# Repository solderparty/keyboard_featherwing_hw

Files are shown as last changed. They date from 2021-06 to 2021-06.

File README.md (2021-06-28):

# The Keyboard FeatherWing (Rev 2)

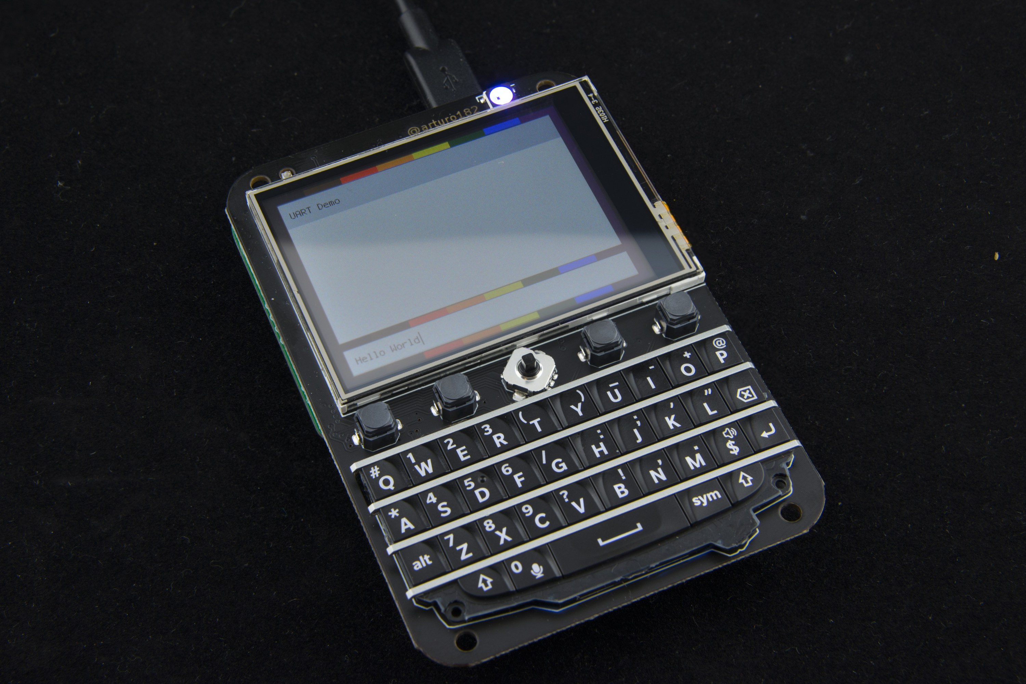
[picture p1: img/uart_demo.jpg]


The Keyboard FeatherWing is an easy way to add a handheld Qwerty keyboard and a 2.6” color display (+ more) to your project! It fits well in your hands and is great for typing with your thumbs, early 2000s-style.

The FeatherWing itself does not contain an MCU/CPU/SoC that you can program; you will need a board compatible with the [Adafruit Feather System](https://learn.adafruit.com/adafruit-feather/feather-specification).

For revision 1, see the tag `rev1`.

# Technical details
- 2.6” 320x240 16-bit color LCD with resistive touch screen
- QWERTY keyboard
- 5-way button
- 4 soft tactile buttons
- A Neopixel
- microSD connector
- Stemma QT/Qwiic connector
- An Ambient Light Sensor
- On/Off switch
- Dual row sockets
- Four mounting holes
- GPIO solder jumpers

# Links

For more information visit https://kfw.solder.party/

You can find example code here: https://github.com/solderparty/keyboard_featherwing_sw

This board uses an ATSAMD20 chip as a i2c peripheral that can be polled to get the key FIFO, as well as used as a simple GPIO Expander, the firmware for the SAM can be found here: https://github.com/solderparty/bbq10kbd_i2c_sw

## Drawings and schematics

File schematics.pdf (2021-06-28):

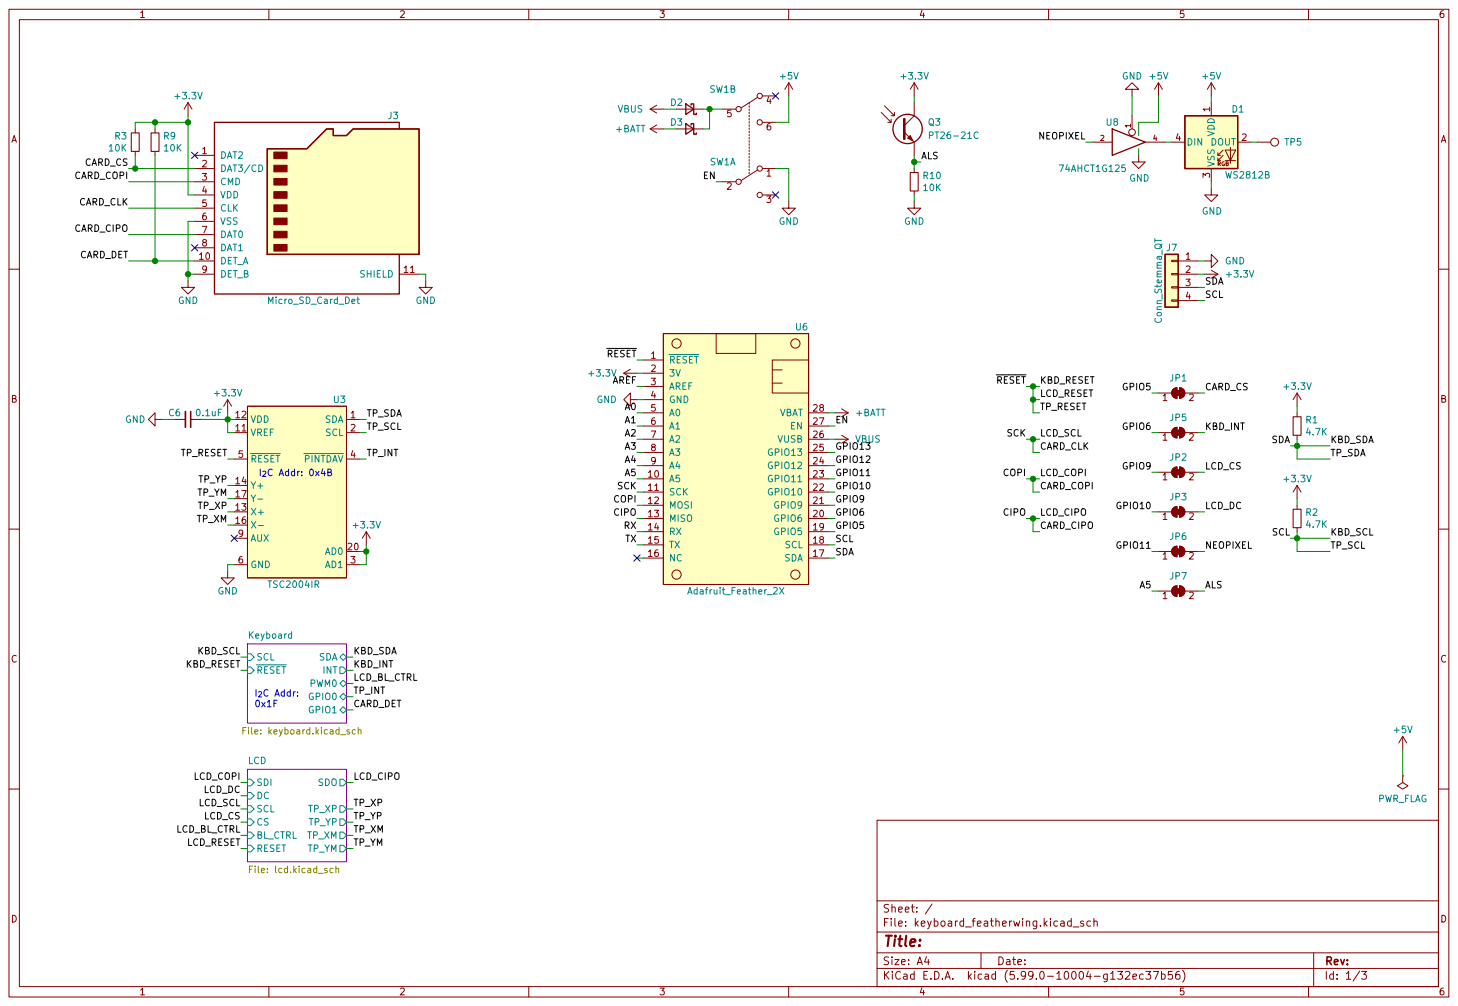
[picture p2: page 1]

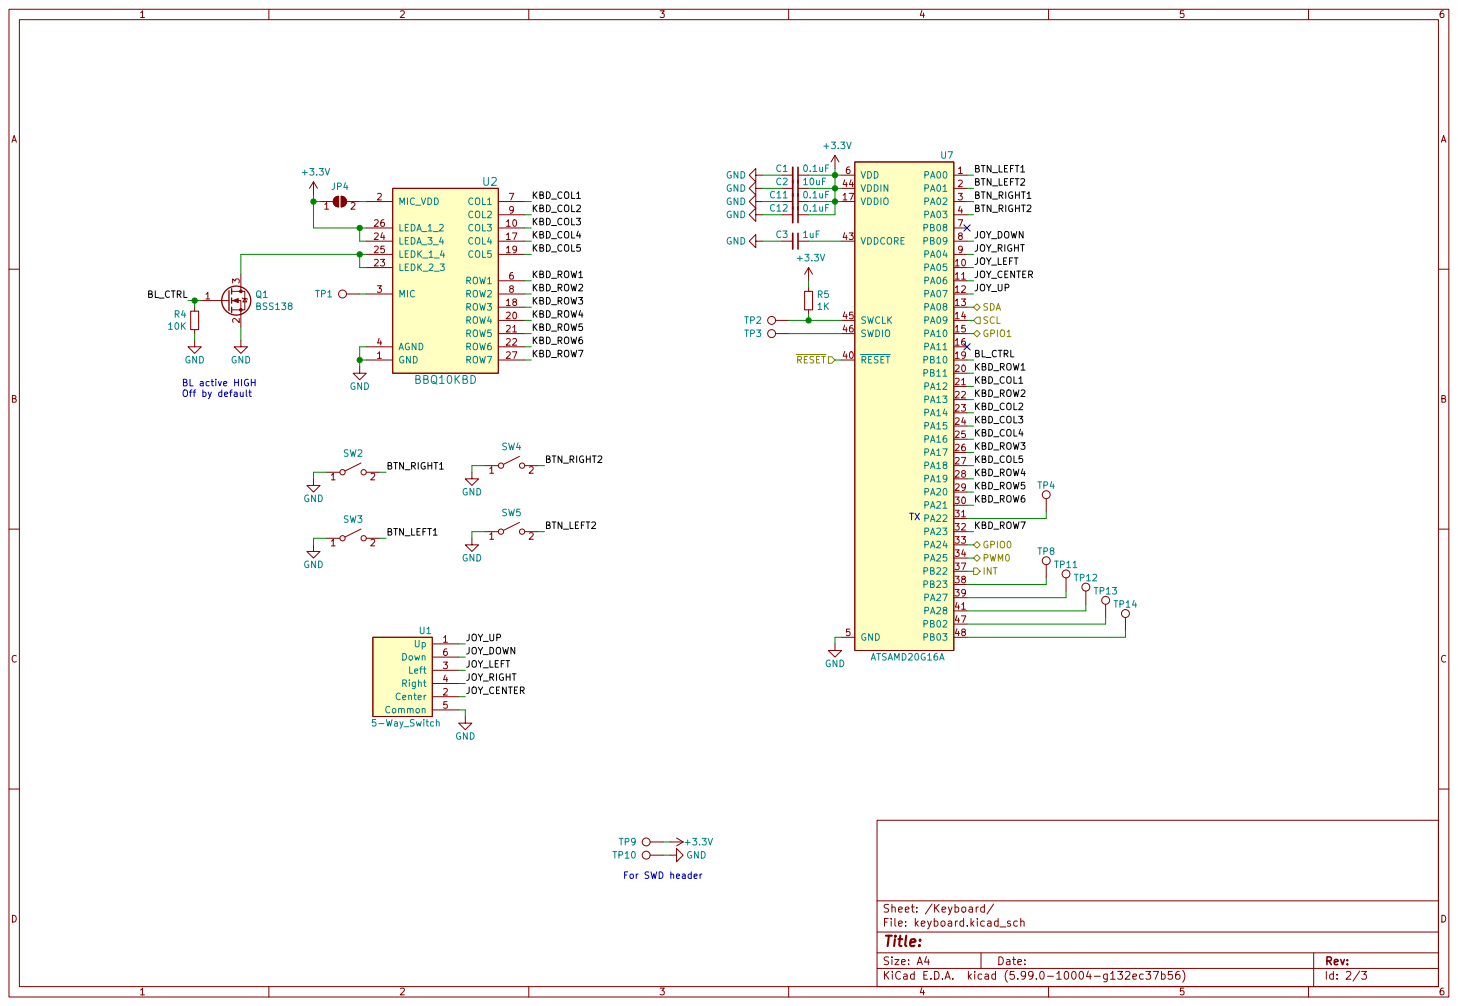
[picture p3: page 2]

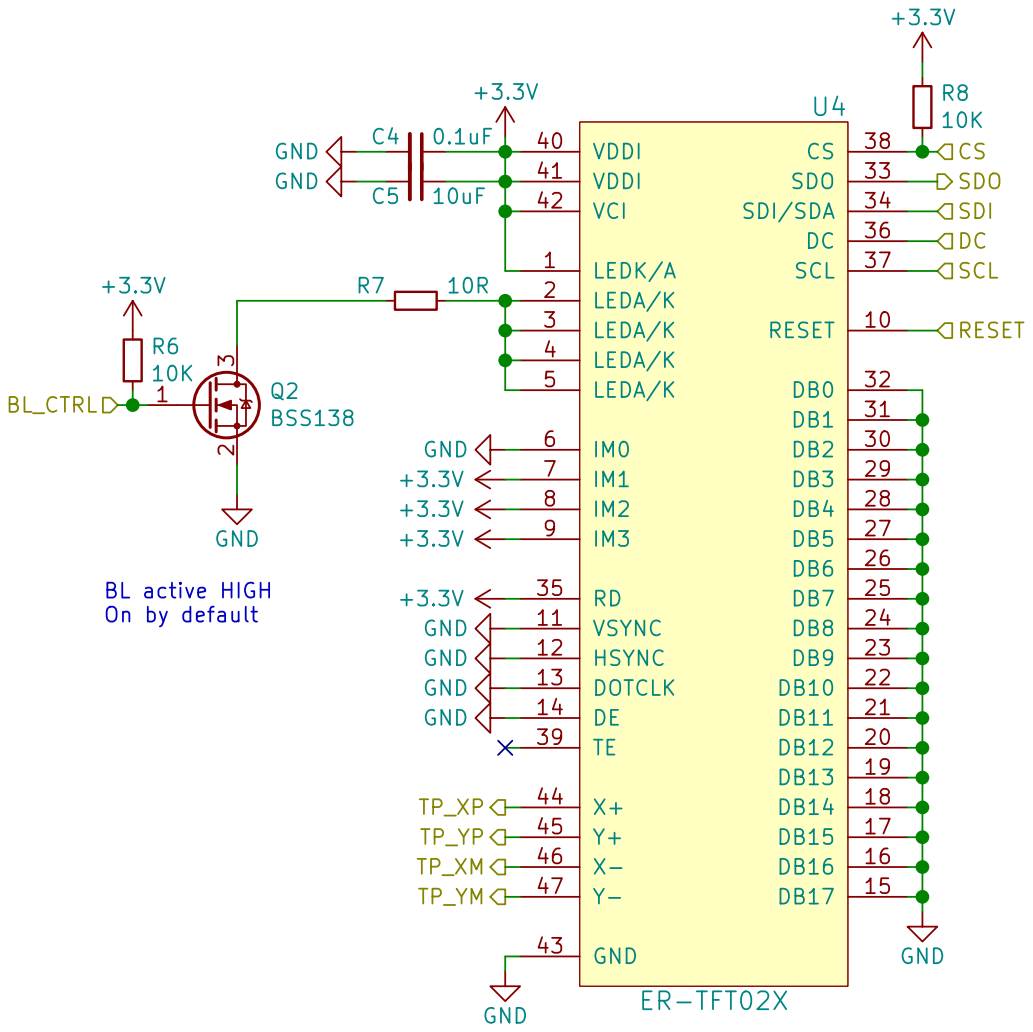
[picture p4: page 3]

File: lcd.kicad_sch Sheet: /LCD/
Id: 3/3 Title:

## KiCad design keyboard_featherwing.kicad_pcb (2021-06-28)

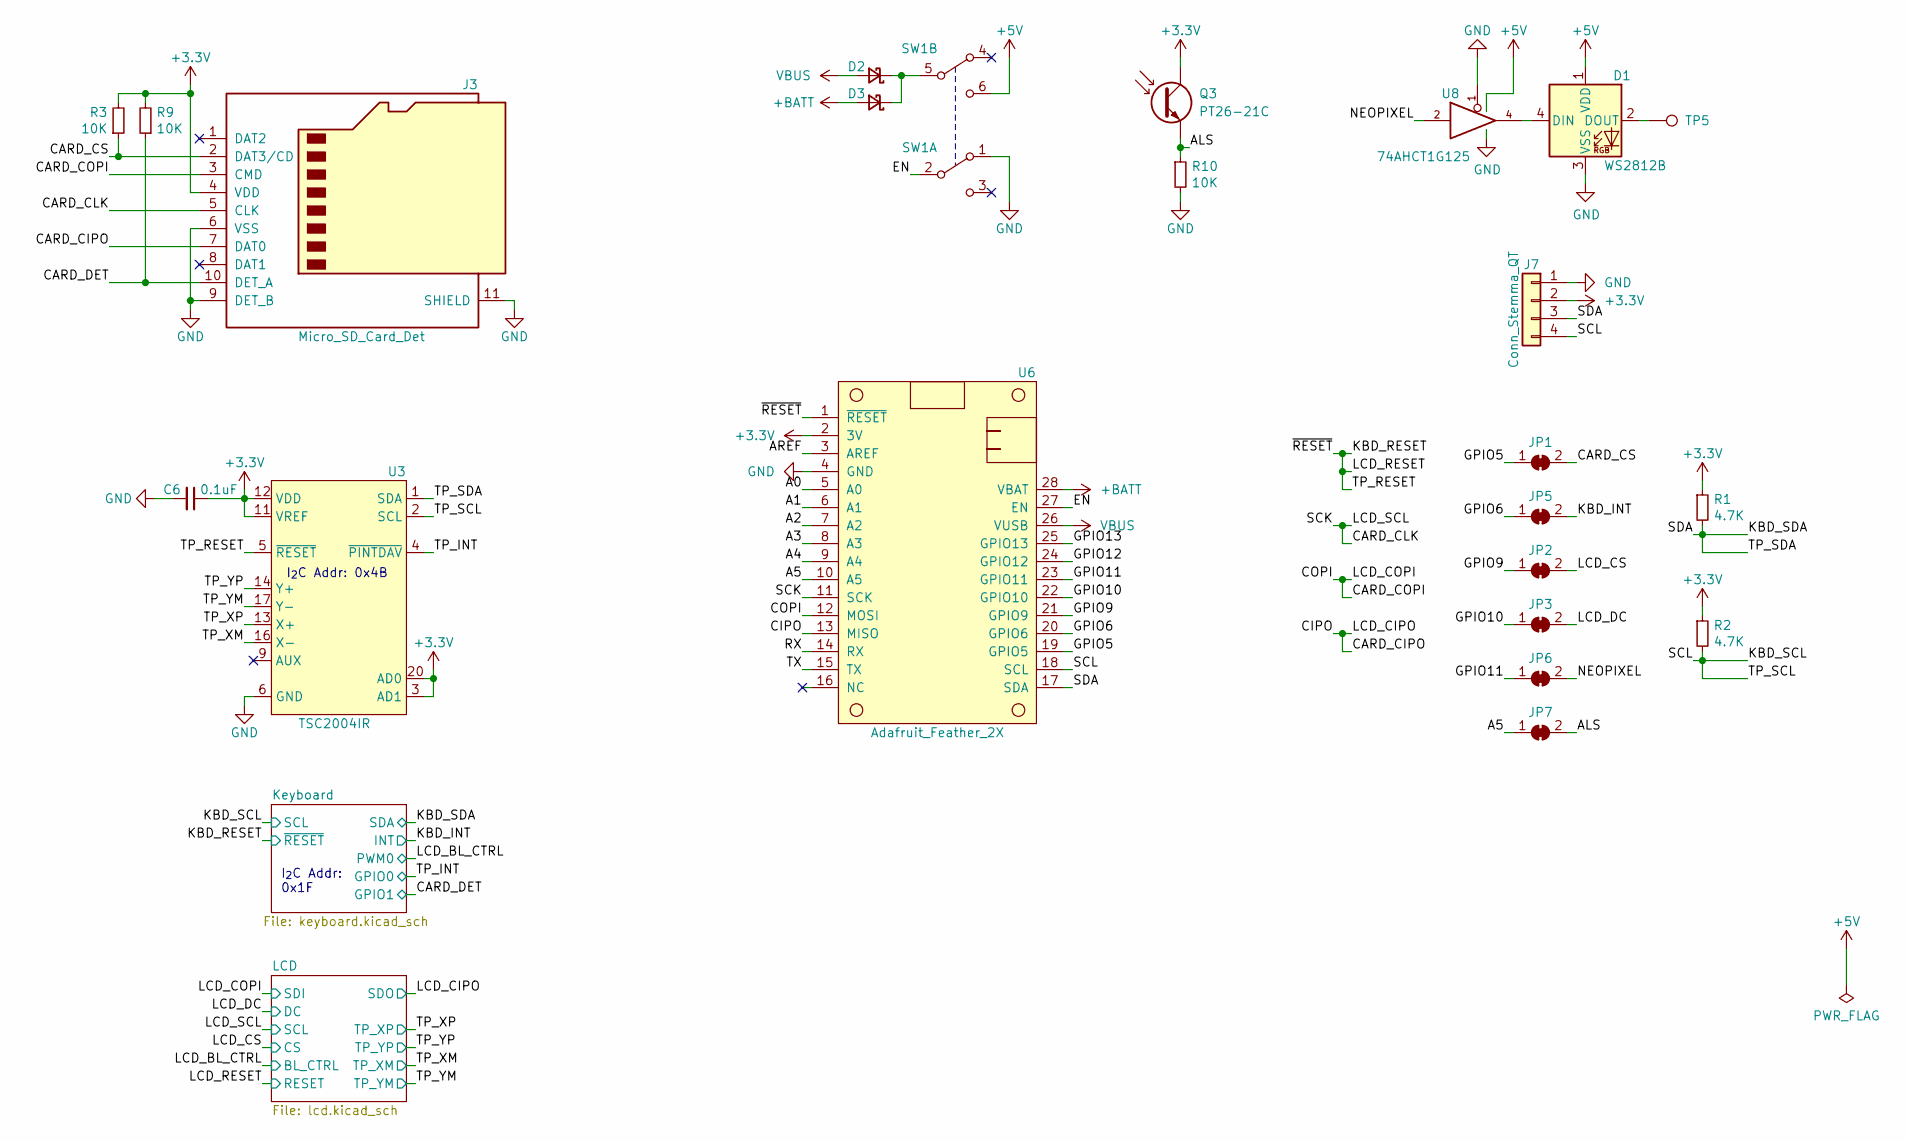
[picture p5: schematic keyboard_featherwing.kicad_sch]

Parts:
C6: 0.1uF; C_0603_1608Metric
D1: WS2812B; LED_WS2812B_PLCC4_5.0x5.0mm_P3.2mm; LCSC C11458
D2, D3: S1JHE; D_SOD-323_HandSoldering; LCSC C114023
J3: Micro_SD_Card_Det; microSD_HC_Molex_104031-0811
J7: Conn_Stemma_QT; JST_SH_SM04B-SRSS-TB_1x04-1MP_P1.00mm_Horizontal; LCSC C145956
JP1: SB_CARD_CS; SolderJumper-2_P1.3mm_Bridged_RoundedPad1.0x1.5mm
JP2: SB_LCD_CS; SolderJumper-2_P1.3mm_Bridged_RoundedPad1.0x1.5mm
JP3: SB_LCD_DC; SolderJumper-2_P1.3mm_Bridged_RoundedPad1.0x1.5mm
JP5: SB_KBD_INT; SolderJumper-2_P1.3mm_Bridged_RoundedPad1.0x1.5mm
JP6: SB_NEOPIXEL; SolderJumper-2_P1.3mm_Bridged_RoundedPad1.0x1.5mm
JP7: SB_ALS; SolderJumper-2_P1.3mm_Bridged_RoundedPad1.0x1.5mm
Q3: PT26-21C; Everlight_PT26-21C
R1, R2: 4.7K; R_0603_1608Metric
R3, R9, R10: 10K; R_0603_1608Metric
SW1: SK-3245S-Lx-B; K3-x245S
TP5: TP_NEOPIXEL_OUT; TestPoint_Pad_D2.0mm
U3: TSC2004IR; QFN-20-1EP_4x4mm_P0.5mm_EP2.7x2.7mm; LCSC C128424
U6: Adafruit_Feather_2X; FeatherWing
U8: 74AHCT1G125; SOT-353_SC-70-5; LCSC C151890

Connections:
+3V3: C6.1, J3.4 (VDD), J7.2, Q3.1, Q3.3, R1.1, R2.1, R3.2, R9.2, U3.3 (AD1), U3.7 (VDD), U3.11 (VREF), U3.12 (VDD), U3.20 (AD0), U6.2 (3V); also elsewhere on the board
+5V: D1.1 (VDD), SW1.6 (C), U8.5 (VCC)
+BATT: D3.2 (A), U6.28 (VBAT)
/A0: U6.5 (A0)
/A1: U6.6 (A1)
/A2: U6.7 (A2)
/A3: U6.8 (A3)
/A4: U6.9 (A4)
/A5: JP7.1 (A), U6.10 (A5)
/ALS: JP7.2 (B), Q3.2, Q3.4, R10.1
/AREF: U6.3 (AREF)
/CARD_CIPO: J3.7 (DAT0), U6.13 (MISO); also elsewhere on the board
/CARD_CLK: J3.5 (CLK), U6.11 (SCK); also elsewhere on the board
/CARD_COPI: J3.3 (CMD), U6.12 (MOSI); also elsewhere on the board
/CARD_CS: J3.2 (DAT3/CD), JP1.2 (B), R3.1
/CARD_DET: J3.10 (DET_A), R9.1; also elsewhere on the board
/EN: SW1.2 (B), U6.27 (EN)
/GPIO5: JP1.1 (A), U6.19 (GPIO5)
/GPIO6: JP5.1 (A), U6.20 (GPIO6)
/GPIO9: JP2.1 (A), U6.21 (GPIO9)
/GPIO10: JP3.1 (A), U6.22 (GPIO10)
/GPIO11: JP6.1 (A), U6.23 (GPIO11)
/GPIO12: U6.24 (GPIO12)
/GPIO13: U6.25 (GPIO13)
/KBD_INT: JP5.2 (B); also elsewhere on the board
/KBD_RESET: U3.5 (~RESET~), U6.1 (~RESET~); also elsewhere on the board
/KBD_SCL: J7.4, R2.2, U3.2 (SCL), U6.18 (SCL); also elsewhere on the board
/KBD_SDA: J7.3, R1.2, U3.1 (SDA), U6.17 (SDA); also elsewhere on the board
/LCD_CS: JP2.2 (B); also elsewhere on the board
/LCD_DC: JP3.2 (B); also elsewhere on the board
/NEOPIXEL: JP6.2 (B), U8.2
/RX: U6.14 (RX)
/TP_INT: U3.4 (~PINTDAV~); also elsewhere on the board
/TP_XM: U3.16 (X-); also elsewhere on the board
/TP_XP: U3.13 (X+); also elsewhere on the board
/TP_YM: U3.17 (Y-); also elsewhere on the board
/TP_YP: U3.14 (Y+); also elsewhere on the board
/TX: U6.15 (TX)
GND: C6.2, D1.3 (VSS), J3.6 (VSS), J3.9 (DET_B), J3.11 (SHIELD), J7.1, R10.2, SW1.1 (A), U3.6 (GND), U3.10 (GND), U3.15 (GND), U3.18 (GND), U3.21 (GND), U6.4 (GND), U8.1, U8.3 (GND); also elsewhere on the board
unnamed: D1.2 (DOUT), TP5.1
unnamed: D1.4 (DIN), U8.4
unnamed: D2.1 (K), D3.1 (K), SW1.5 (B)
VBUS: D2.2 (A), U6.26 (VUSB)

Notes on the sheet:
I_{2}C Addr: 0x1F
I_{2}C Addr: 0x4B

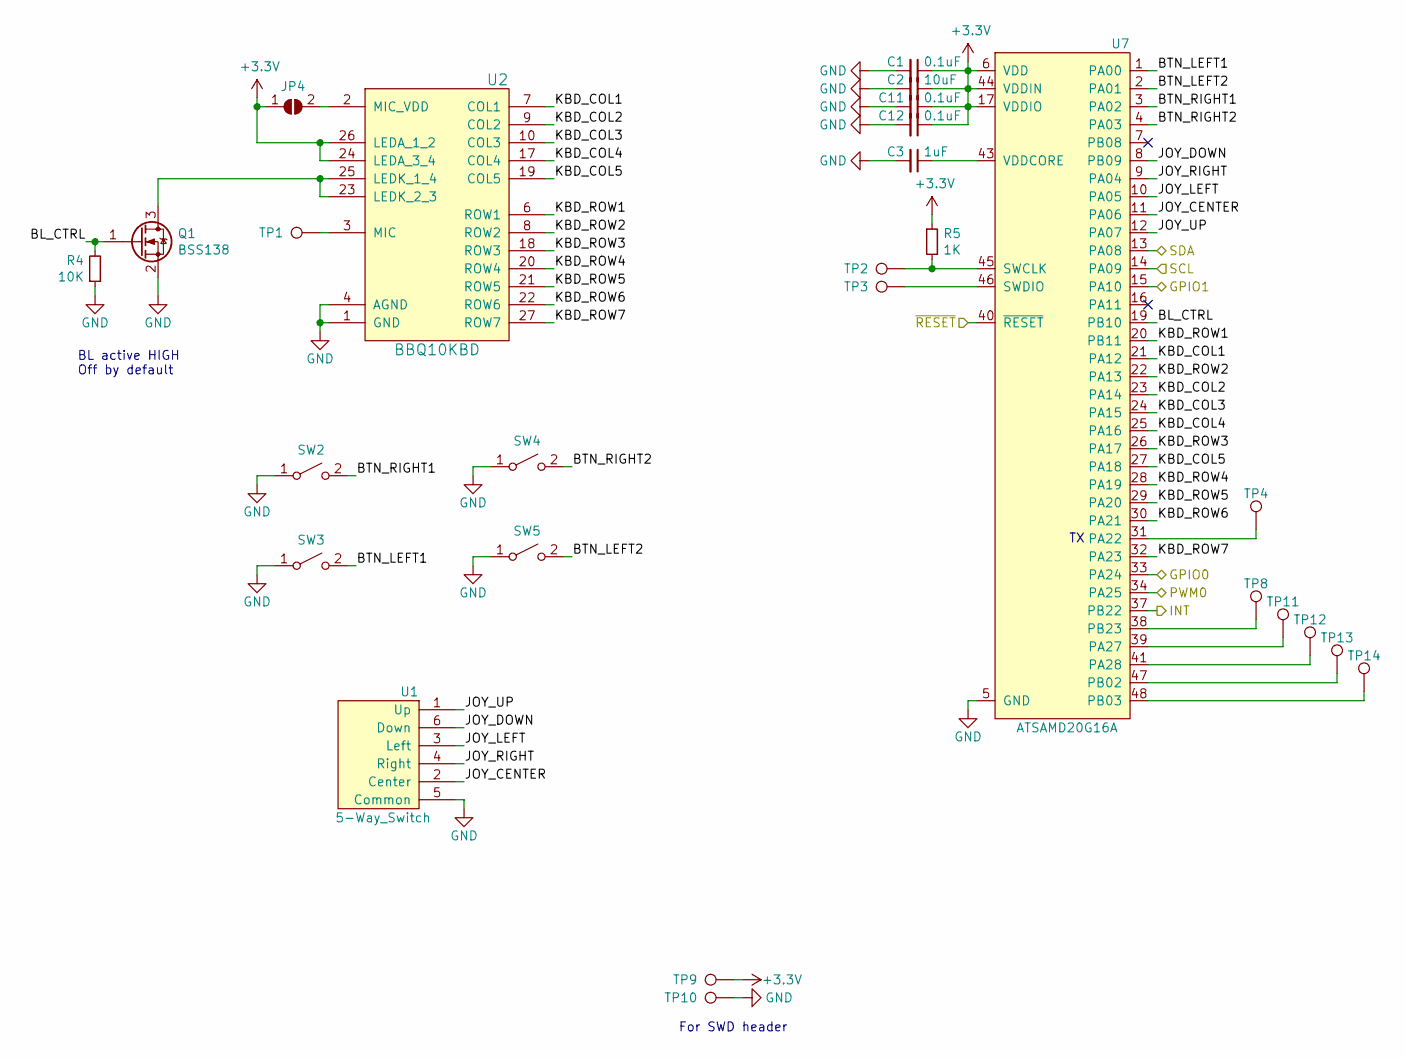
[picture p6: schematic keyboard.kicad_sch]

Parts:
C1, C11, C12: 0.1uF; C_0603_1608Metric
C2: 10uF; C_0603_1608Metric
C3: 1uF; C_0603_1608Metric
JP4: SB_MIC_VDD; SolderJumper-2_P1.3mm_Open_RoundedPad1.0x1.5mm
Q1: BSS138; SOT-23; LCSC C112239
R4: 10K; R_0603_1608Metric
R5: 1K; R_0603_1608Metric
SW2: SW_RIGHT1; RMT-CZ66
SW3: SW_LEFT1; RMT-CZ66
SW4: SW_RIGHT2; RMT-CZ66
SW5: SW_LEFT2; RMT-CZ66
TP1: TP_MIC; TestPoint_Pad_D2.0mm
TP2: TP_KBD_SWCLK; TestPoint_Pad_D2.0mm
TP3: TP_KBD_SWDIO; TestPoint_Pad_D2.0mm
TP4: TP_KBD_TX; TestPoint_Pad_D2.0mm
TP8: TP_GPIO2; TestPoint_Pad_D2.0mm
TP9: TP_KBD_3V; TestPoint_Pad_D2.0mm
TP10: TP_KBD_GND; TestPoint_Pad_D2.0mm
TP11: TP_GPIO3; TestPoint_Pad_D2.0mm
TP12: TP_GPIO4; TestPoint_Pad_D2.0mm
TP13: TP_GPIO5; TestPoint_Pad_D2.0mm
TP14: TP_GPIO6; TestPoint_Pad_D2.0mm
U1: 5-Way_Switch; SF303GJ26
U2: BBQ10KBD; BM14B(0.8)-24DS-0.4V(53)
U7: ATSAMD20G16A; QFN-48-1EP_7x7mm_P0.5mm_EP5.15x5.15mm

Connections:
+3V3: C1.1, C2.1, C11.1, C12.1, JP4.1 (A), R5.1, TP9.1, U2.24 (LEDA_3_4), U2.26 (LEDA_1_2), U7.6 (VDD), U7.17 (VDDIO), U7.36 (VDDIO), U7.44 (VDDIN); also elsewhere on the board
/CARD_DET: U7.15 (PA10); also elsewhere on the board
/KBD_INT: U7.37 (PB22); also elsewhere on the board
/KBD_RESET: U7.40 (~RESET~); also elsewhere on the board
/KBD_SCL: U7.14 (PA09); also elsewhere on the board
/KBD_SDA: U7.13 (PA08); also elsewhere on the board
/Keyboard/BL_CTRL: Q1.1 (G), R4.2, U7.19 (PB10)
/Keyboard/BTN_LEFT1: SW3.2 (B), U7.1 (PA00)
/Keyboard/BTN_LEFT2: SW5.2 (B), U7.2 (PA01)
/Keyboard/BTN_RIGHT1: SW2.2 (B), U7.3 (PA02)
/Keyboard/BTN_RIGHT2: SW4.2 (B), U7.4 (PA03)
/Keyboard/JOY_CENTER: U1.2 (Center), U7.11 (PA06)
/Keyboard/JOY_DOWN: U1.6 (Down), U7.8 (PB09)
/Keyboard/JOY_LEFT: U1.3 (Left), U7.10 (PA05)
/Keyboard/JOY_RIGHT: U1.4 (Right), U7.9 (PA04)
/Keyboard/JOY_UP: U1.1 (Up), U7.12 (PA07)
/Keyboard/KBD_COL1: U2.7 (COL1), U7.21 (PA12)
/Keyboard/KBD_COL2: U2.9 (COL2), U7.23 (PA14)
/Keyboard/KBD_COL3: U2.10 (COL3), U7.24 (PA15)
/Keyboard/KBD_COL4: U2.17 (COL4), U7.25 (PA16)
/Keyboard/KBD_COL5: U2.19 (COL5), U7.27 (PA18)
/Keyboard/KBD_ROW1: U2.6 (ROW1), U7.20 (PB11)
/Keyboard/KBD_ROW2: U2.8 (ROW2), U7.22 (PA13)
/Keyboard/KBD_ROW3: U2.18 (ROW3), U7.26 (PA17)
/Keyboard/KBD_ROW4: U2.20 (ROW4), U7.28 (PA19)
/Keyboard/KBD_ROW5: U2.21 (ROW5), U7.29 (PA20)
/Keyboard/KBD_ROW6: U2.22 (ROW6), U7.30 (PA21)
/Keyboard/KBD_ROW7: U2.27 (ROW7), U7.32 (PA23)
/LCD_BL_CTRL: U7.34 (PA25); also elsewhere on the board
/TP_INT: U7.33 (PA24); also elsewhere on the board
GND: C1.2, C2.2, C3.2, C11.2, C12.2, Q1.2 (S), R4.1, SW2.1 (A), SW3.1 (A), SW4.1 (A), SW5.1 (A), TP10.1, U1.5 (Common), U1.SHIELD, U2.1 (GND), U2.4 (AGND), U2.5 (GND), U2.11 (GND), U2.12 (GND), U2.13 (GND), U2.14 (GND), U2.15 (GND), U2.16 (GND), U2.28 (GND), U7.5 (GND), U7.18 (GND), U7.35 (GND), U7.42 (GND); also elsewhere on the board
unnamed: C3.1, U7.43 (VDDCORE)
unnamed: JP4.2 (B), U2.2 (MIC_VDD)
unnamed: Q1.3 (D), U2.23 (LEDK_2_3), U2.25 (LEDK_1_4)
unnamed: R5.2, TP2.1, U7.45 (SWCLK)
unnamed: TP1.1, U2.3 (MIC)
unnamed: TP3.1, U7.46 (SWDIO)
unnamed: TP4.1, U7.31 (PA22)
unnamed: TP8.1, U7.38 (PB23)
unnamed: TP11.1, U7.39 (PA27)
unnamed: TP12.1, U7.41 (PA28)
unnamed: TP13.1, U7.47 (PB02)
unnamed: TP14.1, U7.48 (PB03)

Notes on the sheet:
BL active HIGH Off by default
For SWD header

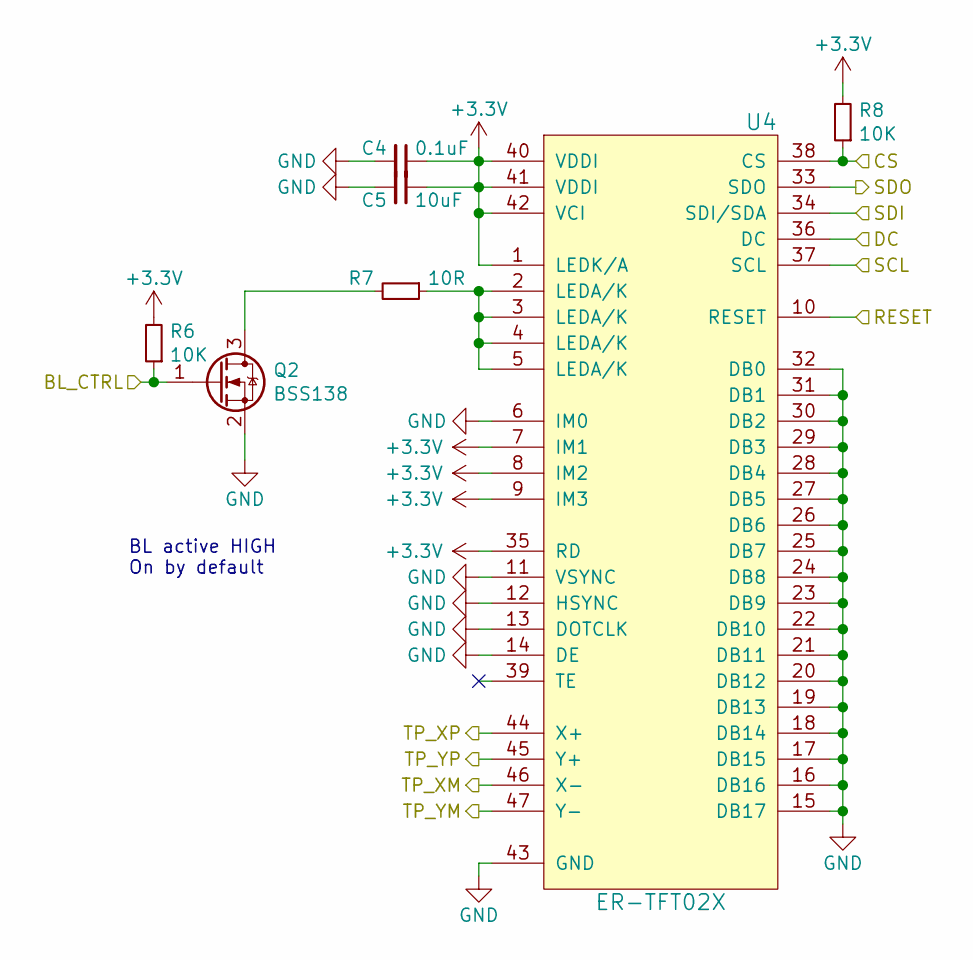
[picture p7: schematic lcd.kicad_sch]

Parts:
C4: 0.1uF; C_0603_1608Metric
C5: 10uF; C_0603_1608Metric
Q2: BSS138; SOT-23; LCSC C112239
R6, R8: 10K; R_0603_1608Metric
R7: 10R; R_0603_1608Metric
U4: ER-TFT02X; ER-CON50HT-1

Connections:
+3V3: C4.1, C5.1, R6.2, R8.2, U4.1 (LEDK/A), U4.7 (IM1), U4.8 (IM2), U4.9 (IM3), U4.35 (RD), U4.40 (VDDI), U4.41 (VDDI), U4.42 (VCI); also elsewhere on the board
/CARD_CIPO: U4.33 (SDO); also elsewhere on the board
/CARD_CLK: U4.37 (SCL); also elsewhere on the board
/CARD_COPI: U4.34 (SDI/SDA); also elsewhere on the board
/KBD_RESET: U4.10 (RESET); also elsewhere on the board
/LCD_BL_CTRL: Q2.1 (G), R6.1; also elsewhere on the board
/LCD_CS: R8.1, U4.38 (CS); also elsewhere on the board
/LCD_DC: U4.36 (DC); also elsewhere on the board
/TP_XM: U4.46 (X-); also elsewhere on the board
/TP_XP: U4.44 (X+); also elsewhere on the board
/TP_YM: U4.47 (Y-); also elsewhere on the board
/TP_YP: U4.45 (Y+); also elsewhere on the board
GND: C4.2, C5.2, Q2.2 (S), U4.6 (IM0), U4.11 (VSYNC), U4.12 (HSYNC), U4.13 (DOTCLK), U4.14 (DE), U4.15 (DB17), U4.16 (DB16), U4.17 (DB15), U4.18 (DB14), U4.19 (DB13), U4.20 (DB12), U4.21 (DB11), U4.22 (DB10), U4.23 (DB9), U4.24 (DB8), U4.25 (DB7), U4.26 (DB6), U4.27 (DB5), U4.28 (DB4), U4.29 (DB3), U4.30 (DB2), U4.31 (DB1), U4.32 (DB0), U4.43 (GND), U4.48 (GND), U4.49 (GND), U4.50 (GND); also elsewhere on the board
unnamed: Q2.3 (D), R7.2
unnamed: R7.1, U4.2 (LEDA/K), U4.3 (LEDA/K), U4.4 (LEDA/K), U4.5 (LEDA/K)

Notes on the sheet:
BL active HIGH On by default

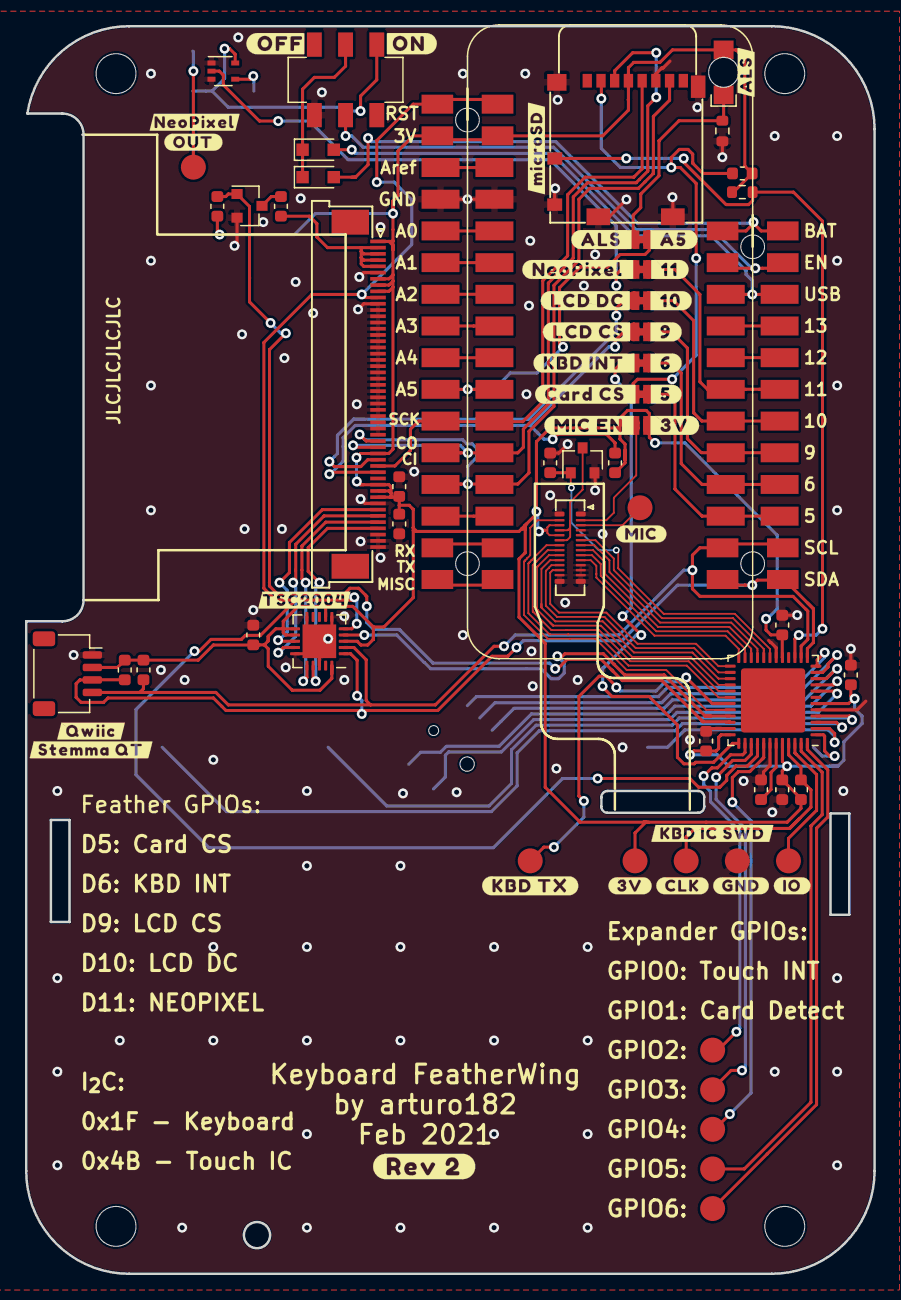
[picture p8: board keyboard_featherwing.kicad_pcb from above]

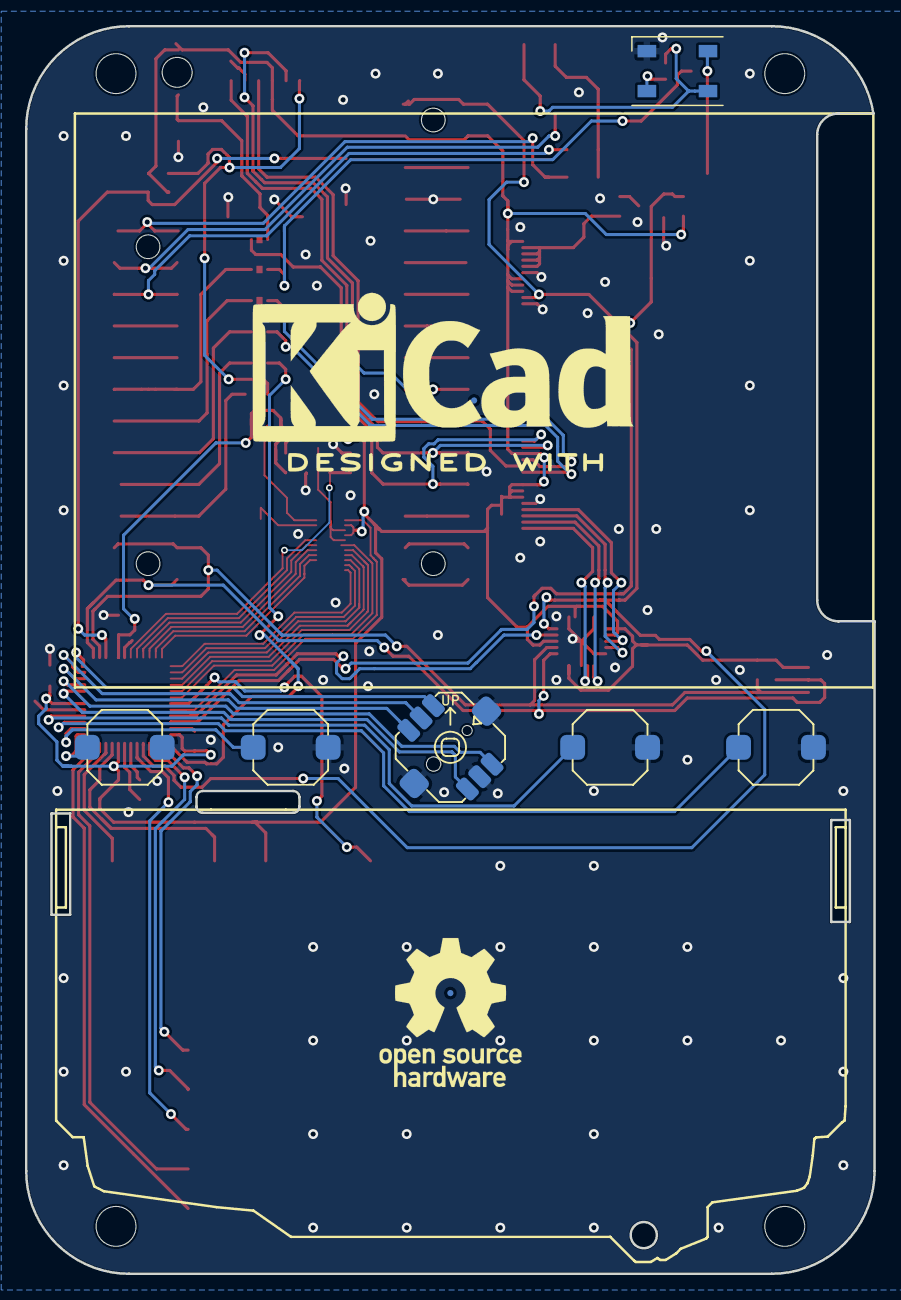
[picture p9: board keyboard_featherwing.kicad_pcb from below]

Board: 2 copper layers, 68.0 x 100.0 mm, 57 parts (6 on the bottom side), 70 nets.

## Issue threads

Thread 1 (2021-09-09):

Suggest adding a Reset switch

rdoursenaud, 2021-09-09:
Having to remove the board equipped with other wings from the keyboard to access the reset switch (To access bootloader mode for example) and putting it back can be cumbersome, especially when debugging builds.
Having the reset switch duplicated on the back of the KFW would be awesome!

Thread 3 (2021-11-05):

Error opening the .pro project file.

ottoskyer, 2021-11-05:
Error opening the .pro project file, as follows:
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
22:29:46: file 'D:\Computer\Micropython\Pico\Pico_example\keyboard_featherwing_hw-master\keyboard_featherwing.kicad_pro', line 1: '=' expected.
..............
22:29:46: file 'D:\Computer\Micropython\Pico\Pico_example\keyboard_featherwing_hw-master\keyboard_featherwing.kicad_pro', line 443: '=' expected.
22:29:46: file 'D:\Computer\Micropython\Pico\Pico_example\keyboard_featherwing_hw-master\keyboard_featherwing.kicad_pro', line 444: '=' expected.
